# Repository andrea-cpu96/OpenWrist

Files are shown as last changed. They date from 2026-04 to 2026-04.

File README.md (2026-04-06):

# OpenWrist  
**An open‑source wristwatch with customizable video playback**

OpenWrist is an open‑hardware and open‑firmware project that transforms a simple digital wristwatch into a creative platform.  
By using a microSD card, users can load their own custom videos, allowing filmmakers, designers, and makers to create a unique *video‑watch* experience.

---

## 🎯 Project Goal
OpenWrist is designed to be a hackable, modular, and fully customizable device.  
The idea is simple: **a wristwatch that becomes a video canvas**, where anyone can upload animations, loops, artwork, or micro‑films.

---

## 🛠️ Key Features
- Video playback from microSD  
- Stable 30 FPS
- Precise RTC
- Accelerometer for turn on via wrist movement
- Fully open‑source firmware and hardware
- Designed for makers, videographers, and digital artists  
- Clear, community‑oriented documentation  

---

## 📦 Repository Structure
```text
OpenWrist/
├── Binaries/
├── Includes/
├── Core/
│   ├── Inc/
│   ├── Src/
│   ├── Startup/
├── Drivers/
├── FATFS/
├── Middlewares/
├── Utilities/
├── Debug/
├── Release/
├── Docs/
├── Lib/
├── Doxyfile
├── OpenWrist.ioc
├── STM32H7B0RBTX_FLASH.ld
└── STM32H7B0RBTX_RAM.ld
```

---

## 🎥 How It Works
1. Insert a microSD card into the device  
2. Load a compatible video (use scripts/mp4ToAvi.py script to convert from .mp4 to compatible .avi frames)  
3. Power on the watch  
4. Enjoy your personalized *video‑watch*  

---

## 🧩 Why OpenWrist
- Minimal, elegant, and modular  
- Designed to evolve over time  
- Ideal for experimenting with video, animation, and digital art  
- Fully open‑source and community‑friendly  

---

## 🏆 OSHlab Contest Participation
This project is submitted to the **OSHlab Open Source Hardware Contest**.  
The open‑source philosophy is at the core of OpenWrist: hardware, firmware, and workflows are documented and freely accessible.

---

## 📜 License

---

## 🤝 Contributing
Contributions, forks, and ideas are welcome.  
If you want to propose improvements, feel free to open an issue or submit a pull request.

---

## 📬 Contact

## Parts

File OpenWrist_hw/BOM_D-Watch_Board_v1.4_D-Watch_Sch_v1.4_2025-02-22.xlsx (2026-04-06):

No. | Quantity | Comment | Designator | Footprint | Value | Manufacturer Part | Manufacturer | Supplier Part | Supplier
1 | 3 | 436333033816 | BTN1,BTN2,BTN3 | SW-SMD_436333033816 |  | 436333033816 | Wurth(伍尔特) | C6069361 | LCSC
2 | 13 | 100nF | C1,C2,C3,C4,C5,C6,C7,C8,C10,C11,C21,C22,C23 | C0603 | 100nF | GCJ188R71C104KA01D | muRata(村田) | C710619 | LCSC
3 | 1 | 4.7uF | C9 | C0603 | 4.7uF | GCJ188C70J475KE02D | muRata(村田) | C437419 | LCSC
4 | 3 | 1uF | C12,C13,C14 | C0603 | 1uF | CC0603KRX7R5BB105 | YAGEO(国巨) | C309479 | LCSC
5 | 3 | 10uF | C15,C16,C17 | CAP-SMD_L1.6-W0.8-RD | 10uF | T58MM106M6R3C0300 | VISHAY(威世) | C2158420 | LCSC
6 | 2 | 12pF | C18,C19 | C0603 | 12pF
7 | 2 | 1uF | C20,C25 | C0603 | 1uF | AC0603KRX7R6BB105 | YAGEO(国巨) | C726554 | LCSC
8 | 1 | 53398-0771 | CN1 | CONN-SMD_7P-P1.25_53398-0771 |  | 533980771 | MOLEX | C240849 | LCSC
9 | 1 | TDZ3V6J,115 | D1 | SOD-323_L1.7-W1.3-LS2.5-RD-1 |  | TDZ3V6J,115 | Nexperia(安世) | C553831 | LCSC
10 | 1 | 2.54-1*2P母 | H9 | HDR-TH_2P-P2.54-V-F |  | 2.54-1*2P母 | BOOMELE(博穆精密) | C49661 | LCSC
11 | 1 | HDR-M_2.54_1x12P | H10 | HDR-TH_12P-P2.54-V-M
12 | 1 | APT1608MGC | LEDG1 | LED-SMD_L1.6-W0.8-RD |  | APT1608MGC | Kingbright | C5554150 | LCSC
13 | 1 | APT1608SURCK | LEDR1 | LED0603-RD |  | APT1608SURCK | Kingbright | C5875723 | LCSC
14 | 1 | NSS40200LT1G | Q2 | SOT-23-3_L2.9-W1.3-P1.90-LS2.4-BR |  | NSS40200LT1G | onsemi(安森美) | C232571 | LCSC
15 | 1 | 470R | R1 | R0603 | 470R
16 | 2 | 10K | R2,R4 | R0603 | 10K
17 | 1 | 2k | R3 | R0603 | 2k
18 | 5 | 330R | R5,R13,R14,R15,R28 | R0603 | 330R
19 | 3 | 10k | R6,R7,R31 | R0603 | 10k
20 | 1 | 51R | R8 | R0603 | 51R
21 | 1 | 8.2k | R9 | R0603 | 8.2k
22 | 1 | 4.3k | R10 | R0603 | 4.3k
23 | 1 | 50R | R11 | R0603 | 50R
24 | 2 | 100k | R12,R30 | R0603 | 100k
25 | 6 | 22R | R16,R17,R18,R19,R20,R21 | R0603 | 22R
26 | 1 | 1.8k | R27 | R0603 | 1.8k
27 | 1 | 5k | R29 | R0603 | 5k
28 | 2 | 4.7k | R33,R34 | R0603 | 4.7k
29 | 1 | Test-Point | TP1 | Test-Point-0.5mm
30 | 1 | LP3874EMP-3.3_NOPB_ | U4 | SOT150P700X180-5N
31 | 1 | BQ24092DGQR | U5 | MSOP-10_L3.0-W3.0-P0.50-LS5.0-BL-EP |  | BQ24092DGQR | TI(德州仪器) | C133237 | LCSC
32 | 1 | DM3BT-DSF-PEJS_ | U8 | DM3BTDSFPEJS
33 | 1 | STM32H7B0RBT6 | U10 | LQFP-64_L10.0-W10.0-P0.50-LS12.0-BL |  | STM32H7B0RBT6 | ST(意法半导体) | C730226 | LCSC
34 | 1 | FXLS8974CFR3 | U11 | DFN-10_L2.0-W2.0-P0.40-BL |  | FXLS8974CFR3 | NXP(恩智浦) | C5190703 | LCSC
35 | 1 | 10118192-0001LF | USB1 | MICRO-USB-SMD_10118192-0001LF_1 |  | 10118192-0001LF | Amphenol | C132564 | LCSC
36 | 1 | 32.768kHz | X1 | CRYSTAL-SMD_L3.2-W1.5-1 | 32.768kHz | NX3215SA-32.768K-STD-MUA-9 | NDK | C519280 | LCSC
37 | 1 | EC5625ETTTS-25.000M_TR_ | X2 | EC5625ETTTS25000MTR

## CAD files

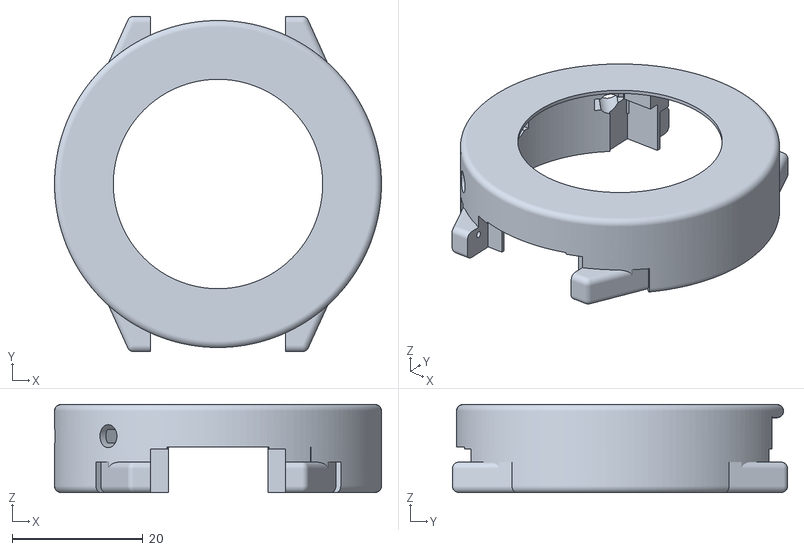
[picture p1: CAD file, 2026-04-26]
OpenWrist_3D_enclosure/enclosure_top.stl
50.0 x 51.2 x 13.5

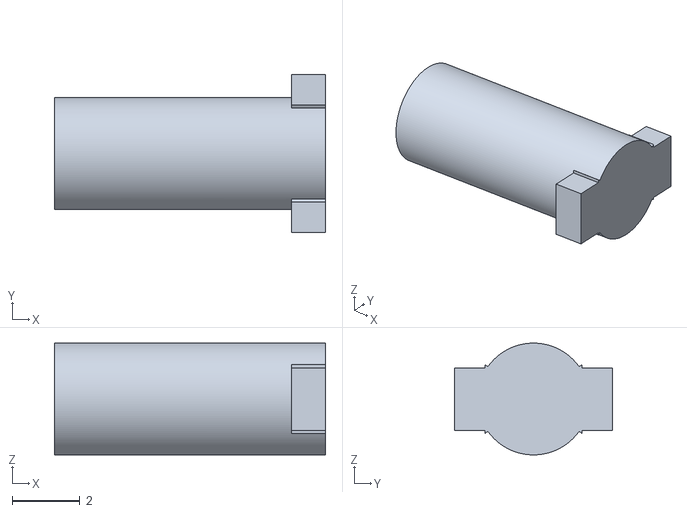
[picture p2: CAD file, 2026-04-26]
OpenWrist_3D_enclosure/botton.stl
8.00 x 4.65 x 3.30

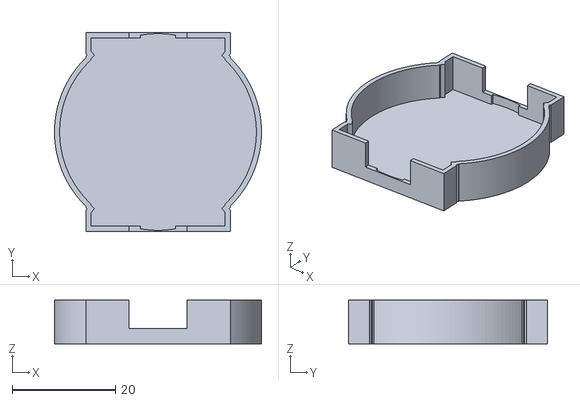
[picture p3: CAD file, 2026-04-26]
OpenWrist_3D_enclosure/enclosure_bottom.stl
40.1 x 38.5 x 8.50

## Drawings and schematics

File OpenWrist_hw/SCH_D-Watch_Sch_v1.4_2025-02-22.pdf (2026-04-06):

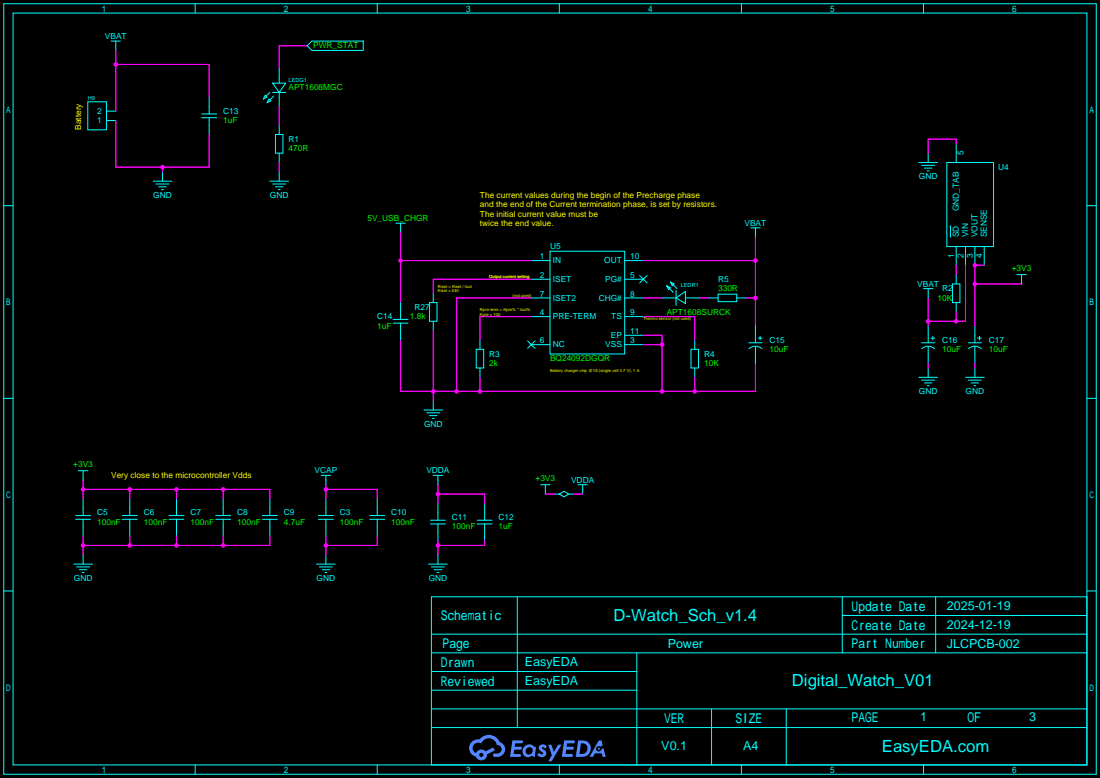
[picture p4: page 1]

The current values during the begin of the Precharge phase
and the end of the Current termination phase, is set by resistors.
The initial current value must be
twice the end value.

Rpre-term = Kpre% * Iout%
Kpre = 100

Thermo sensor (not used)

Battery charger chip @1S (single cell 3.7 V), 1 A

Very close to the microcontroller Vdds

PB12 33 PB13 34 PB14 35 PB15 36 PC6 37 PC7 38 PC9 39 PA8 40 PA9 41 PA10 42 PA11 43 PA12 44 PA13 45 VCAP 46 VSS 47 VDD 48 PA¹⁴ ⁴⁹ PA¹⁵ ⁵⁰

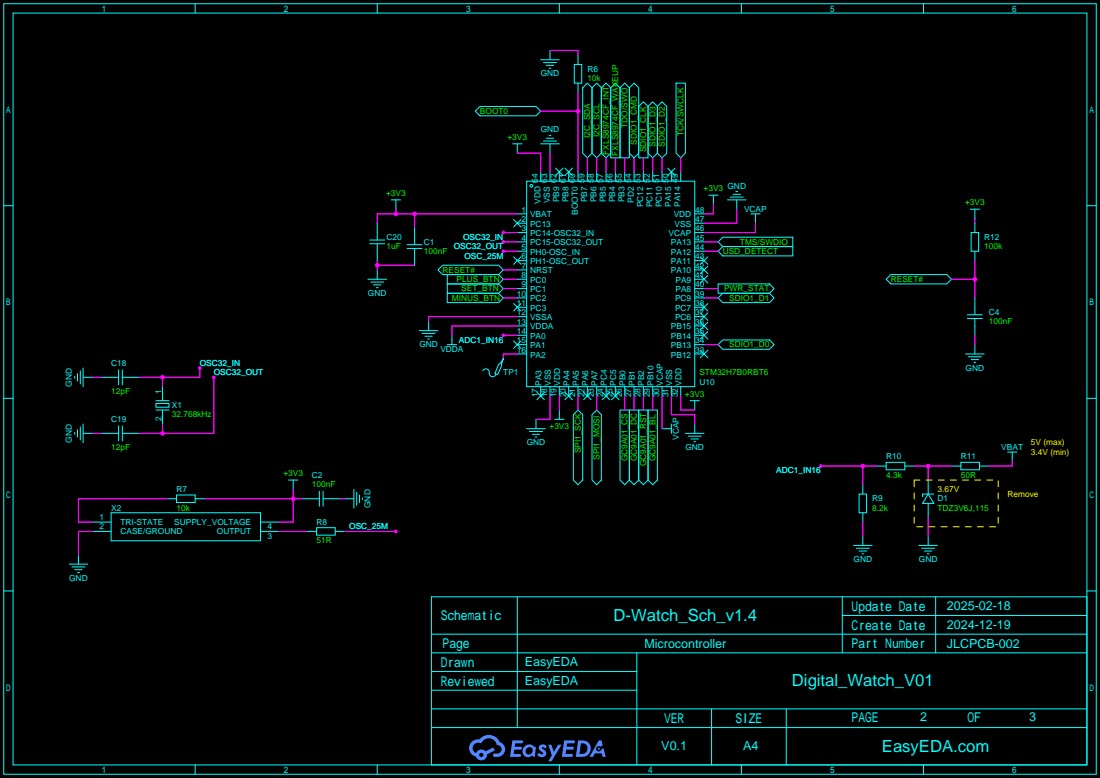
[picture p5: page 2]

# Display

# User buttons

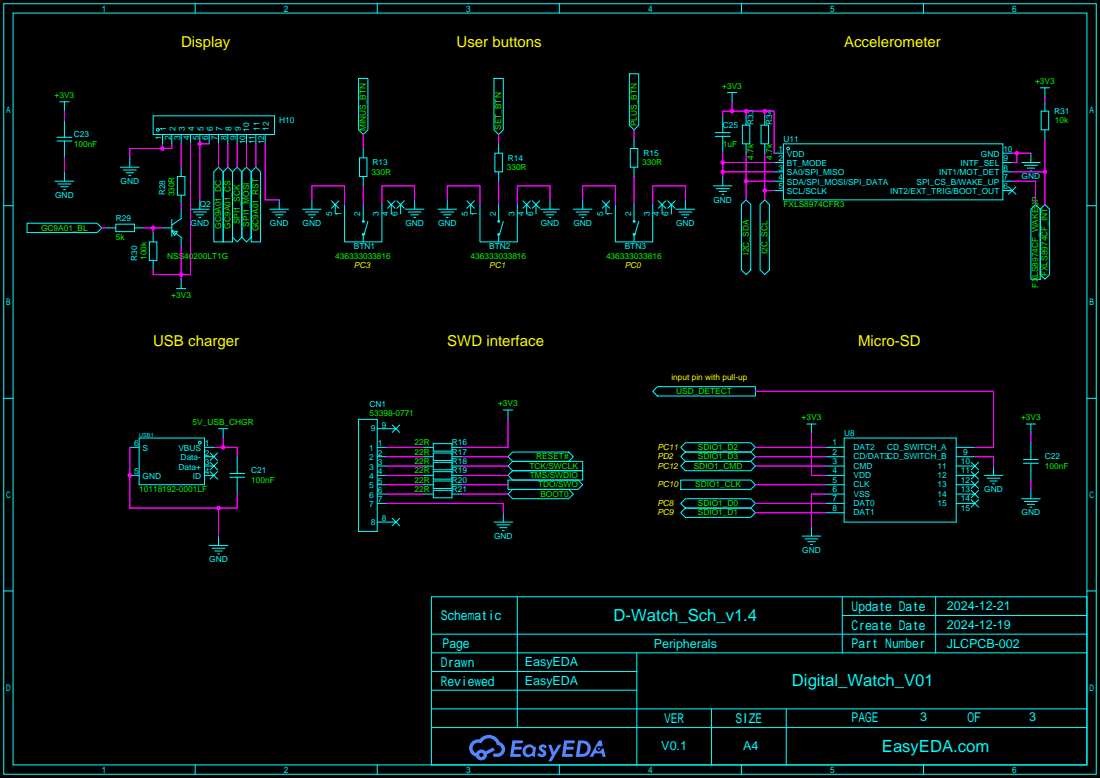
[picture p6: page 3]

input pin with pull-up
USD_DETECT

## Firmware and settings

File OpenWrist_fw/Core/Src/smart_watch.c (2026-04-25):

/*
 * smart_watch.c
 *
 *  Created on: Jul 22, 2024
 *      Author: Fato
 */

/* Includes ------------------------------------------------------------------*/

#include <stdio.h>
#include <string.h>

#include "smart_watch.h"

#include "main.h"
#include "decode_dma.h"
#include "AVI_parser.h"
#include "fatfs.h"

#define DIR_MAX_NUM	10
#define FILE_NUM 720  // 1h = 720 minutes, so 720 files of 1 minute each
#define ROOT_PATH "0:/"

#define OFFSET_FACTOR 0.341 // ( 1 / 3 ): 1 min every 3 days
#define MAX_ATTEMPTS_NUM 10
#define MAX_ITERATIONS_NUM 1000000
#define BTN_INT_DEBOUNCE_MS 200

/* Private typedef -----------------------------------------------------------*/

/* Private define ------------------------------------------------------------*/

/* Private macro -------------------------------------------------------------*/

/* Private variables ---------------------------------------------------------*/

/** Number of days per month */
const uint8_t num_of_days_per_month[12] = {31, 28, 31, 30, 31, 30, 31, 31, 30, 31, 30, 31};

/** Set button status */
volatile enum button_status btn_status = BTN_NONE;

/** Last button interrupt tick for debounce */
static uint32_t last_btn_int_tick = 0;

/** File name */
char name[14];

/** Directories list */
struct dir_list_st
{
	char name[50];
}dir_list[DIR_MAX_NUM];

/** Number of directories */
uint8_t dir_count = 0;

/** Directory selected flag */
uint8_t dir_selected = 0;

/** Seected directory path name */
char dir_path[64] = ROOT_PATH;

/** Number of files in selected directory */
uint16_t file_count = 0;

/** File system object for SD card logical drive */
FATFS SDFatFs;
/** MJPEG File object */
FIL MJPEG_File;
/** AVI Parser Handle */
AVI_CONTEXT AVI_Handel;

/** Video buffer */
uint8_t MJPEG_VideoBuffer[MJPEG_VID_BUFFER_SIZE];
/** Audio buffer */
uint8_t MJPEG_AudioBuffer[MJPEG_AUD_BUFFER_SIZE];

/** Video data structure */
video_t video;

/** Pre elaborated data buffer */
uint8_t preElab_data[300 * 1024];
/** Output data buffer 1 (format RGB565) */
uint8_t output_data1[LCD_SIDE_SIZE * LCD_SIDE_SIZE * 3 + 100];
/** Output data buffer 2 (format RGB565) */
uint8_t output_data2[LCD_SIDE_SIZE * LCD_SIDE_SIZE * 3 + 100];
/** Pointer to the output data buffer */
uint8_t *outputData = output_data1;

/** Watch time */
volatile time_t time;

#ifdef OPT3
block_t pixel_blocks[BLOCK_NUM];
#endif

/** Pointer to the accelerometer handler */
fxls8974_i2c_sensorhandle_t *pAcc_Handle;

/** Accelerometer interrupt flag */
volatile uint8_t acc_int = 0;
/** Wake up flag */
volatile uint8_t wake_up = 0;

/* Private function prototypes -----------------------------------------------*/

/** @brief Initialize DMA2D with given parameters */
static void DMA2D_Init(uint16_t xsize, uint16_t ysize, uint32_t ChromaSampling);

/** @brief Copy buffer using DMA2D */
static void DMA2D_CopyBuffer(uint32_t *pSrc, uint32_t *pDst, uint16_t ImageWidth, uint16_t ImageHeight);

/** @brief Initialize SD card */
static void SD_Initialize(void);

/** @brief Reset parameters */
static void parameters_reset(void);

/** @brief Process MJPEG video */
static int mjpeg_video_processing(void);

/** @brief Handle file operations */
static int file_handler(uint8_t openFile);

/** @brief Manage battery status */
static int battery_management(void);

/** @brief Directory selection */
static void select_dir(void);

/** @brief Set clock settings */
static int clock_setting(void);

/** @brief Normal clock operation */
static int clock_normal(void);

/** @brief Convert 24-bit depth to 16-bit depth */
static void depth24To16(doubleFormat *pxArr, uint16_t length, uint8_t bpx);

/** @brief Show a specific frame */
static int show_frame(uint32_t frame_num);

/** @brief Enable accelerometer interrupt */
static void enable_accel_int(void);

/** @brief Disable accelerometer interrupt */
static void disable_accel_int(void);

/** @brief Enable button interrupt */
static void enable_btn_int(void);

/** @brief Disable button interrupt */
static void disable_btn_int(void);

/** @brief Clear button interrupt */
static void clear_btn_int(void);

/** @brief Reset digital watch clock if needed */
static void clock_reset_check(void);

/** @brief Check battery status */
static int check_battery_status(void);

/** @brief Resume time from saved state */
static void resume_time(void);

/** @brief Check accelerometer gesture */
static uint8_t check_accel_gesture(void);

/** @brief Get sub directories list */
static int get_sub_dir(void);

/** @brief Count files in a directory */
static uint16_t count_files_in_dir(const char *path);

/** @brief Draw directory selection UI */
static void select_dir_draw(uint8_t dir_idx);

/** @brief Draw a single pixel in RGB565 format */
static int lcd_draw_pixel(uint16_t x, uint16_t y, uint16_t color);

/** @brief Return 5x7 glyph columns for supported ASCII characters */
static const uint8_t *get_glyph_5x7(char c);

/** @brief Draw a single 5x7 character */
static int lcd_draw_char(uint16_t x, uint16_t y, char c, uint16_t color, uint16_t bg_color);

/** @brief Draw a scaled 5x7 character */
static int lcd_draw_char_scaled(uint16_t x, uint16_t y, char c, uint16_t color, uint16_t bg_color, uint8_t scale);

/** @brief Draw a scaled text string using a tiny 5x7 bitmap font */
static int lcd_draw_string_scaled(uint16_t x, uint16_t y, const char *str, uint16_t color, uint16_t bg_color, uint8_t scale);

/* External functions --------------------------------------------------------*/

/**
 * @brief smart_watch_init
 *
 * @return int
 */
int smart_watch_init(void)
{
	parameters_reset();

	disable_accel_int();

	pAcc_Handle = (fxls8974_i2c_sensorhandle_t *)get_acc_addr();

	if (FXLS8974_I2C_Configure(pAcc_Handle) != 1)
		return 0;

#ifdef OPT3
	for (int i = 0; i < BLOCK_NUM; i++)
	{
		uint32_t idx = (i % BLOCKS_PER_RAW);
		uint32_t idy = (i / BLOCKS_PER_RAW);

		pixel_blocks[i].display_frame.start.X = (idx * BLOCK_SIDE_SIZE);
		pixel_blocks[i].display_frame.start.Y = (idy * BLOCK_SIDE_SIZE);
		pixel_blocks[i].display_frame.end.X = ((idx + 1) * BLOCK_SIDE_SIZE - 1);
		pixel_blocks[i].display_frame.end.Y = ((idy + 1) * BLOCK_SIDE_SIZE - 1);

		for (int j = 0; j < BLOCK_SIDE_SIZE; j++)
		{
			uint32_t base_idx = (pixel_blocks[i].display_frame.start.X +
								 (pixel_blocks[i].display_frame.start.Y * LCD_SIDE_SIZE));
			uint32_t line_offs = (j * LCD_SIDE_SIZE);
			uint32_t arr_idx = (base_idx + line_offs);

			pixel_blocks[i].buffer_frame1[j] = &output_data1[arr_idx * 2];
			pixel_blocks[i].buffer_frame2[j] = &output_data2[arr_idx * 2];
		}
	}
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

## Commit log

2026-04-06 Add hw project from local
    [BOM_D-Watch_Board_v1.4_D-Watch_Sch_v1.4_2025-02-22.xlsx, PickAndPlace_D-Watch_PCB_v1.4_2025-02-22.xlsx]
2026-04-22 Fix loop based on the number of available files
    [smart_watch.c]
2026-04-22 Fix bug first frame must be shown after video selection
    [smart_watch.c]
2026-04-22 Fix bug accelerometers pin status bloks button interrupt callbacks
    [smart_watch.c]
2026-04-26 Add 3D enclosure
    [botton.stl, enclosure_bottom.stl, enclosure_top.stl]
